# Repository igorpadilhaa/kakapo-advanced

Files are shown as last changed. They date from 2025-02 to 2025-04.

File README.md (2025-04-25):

---

# Projeto-VictorC-RyanK-IgorP_UFRR_2024

<br />  
<p align="center">
  <a href="">
    
    
    
  </a>
  <h1 align="center">Projeto Pulseira Inteligente</h1>
  <p align="center">
    
  </p>

## 1. Pulseira Inteligente para Monitoramento de Temperatura e Cor da Pele

O projeto consiste no desenvolvimento de uma **pulseira inteligente** para monitoramento de **temperatura corporal** e **variação na coloração da pele**, com foco na **detecção de icterícia e cianose**, utilizando o microcontrolador **ESP32 Pico**.

### 1.1 Objetivos:
- Criar uma pulseira vestível e funcional para uso em ambientes de saúde pública.
- Monitorar a temperatura corporal utilizando sensor **NTC de 5k**.
- Analisar a coloração da pele com o sensor **TCS3200**.
- Utilizar inteligência artificial para identificar variações de cor associadas a **icterícia** e **cianose**.
- Estimar o **grau de variação** da coloração da pele: `Estável`, `Leve`, `Mediana` ou `Alta`.
- Permitir identificação rápida do paciente via **tag RFID**.

## 2. Fluxo de Uso:
- O paciente recebe uma pulseira com sua tag RFID.
- A pulseira coleta periodicamente a **temperatura corporal** e a **cor da pele (RGB)**.
- Os dados são enviados para o banco de dados em nuvem.
- A **IA processa os dados** e identifica se há variação significativa na cor da pele.
- Se detectada, a IA classifica:
  - **Se é icterícia ou cianose**.
  - **Grau da variação** da condição.

## 3. Funcionamento:
- A pulseira tem um ID único salvo em sua tag RFID.
- Os dados coletados (temperatura e cor da pele) são enviados via Wi-Fi para o **Realtime Database**.
- O sensor **TCS3200** coleta as cores RGB da pele.
- Uma **rede neural** compara os valores anteriores e atuais, enquanto uma **floresta randômica (Random Forest)** classifica o **grau da alteração**.
- O sistema já é capaz de identificar casos de:
  - **Icterícia** (coloração amarelada)
  - **Cianose** (coloração azulada)
- A pulseira pode ser lida com um dispositivo com leitor RFID e display, que consulta os dados do paciente diretamente no banco de dados.

## 4. Tutorial de Montagem:
- **NTC de 5k (Sensor de Temperatura)**: Conectar ao pino **23** do ESP32 Pico. Utilizar resistor de **5kΩ** em paralelo.
- **Sensor TCS3200 (Sensor de Cor)**: Conectar os pinos S0–S3 e OUT aos pinos digitais do ESP32 Pico.
- **RFID**: Utilizar um leitor compatível com SPI, conectando os pinos ao ESP32 Pico.
- **Alimentação**: Bateria ligada ao **TP4056**, passando por um **switch**, conectando ao **VIN (5V)** do ESP32.
- **Botão**: Um lado no **GND**, outro na **porta 2** do ESP32.
- **LED Indicador**: Com resistor de **330Ω**, conectado à **porta 4** do ESP32.

## 5. Mudanças Implementadas:
- Substituição do Arduino Mega pelo **ESP32 Pico**.
- **Remoção do aplicativo de monitoramento**.
- **Remoção do sensor de batimentos MAX30100**.
- **Adição do sensor TCS3200** para análise da coloração da pele.
- **Implementação da IA** (rede neural + floresta randômica).
- Sistema já é capaz de **detectar e classificar** casos de **icterícia e cianose** com base na variação da cor da pele.

## 6. Possíveis Atualizações Futuras:
- Adição do sensor **MAX30120** para retomada do monitoramento cardíaco.
- Expansão do modelo de IA para detecção de **doenças dermatológicas mais complexas**, como **câncer de pele**.
- Melhorias no consumo de energia e integração de baterias recarregáveis de longa duração.

---

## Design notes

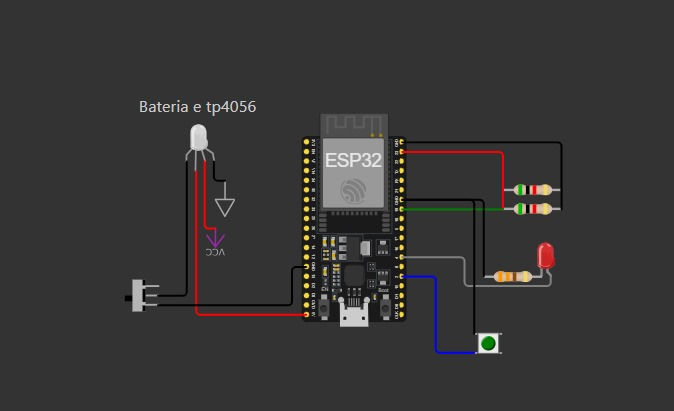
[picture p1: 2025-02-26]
Imagens/circuito.png

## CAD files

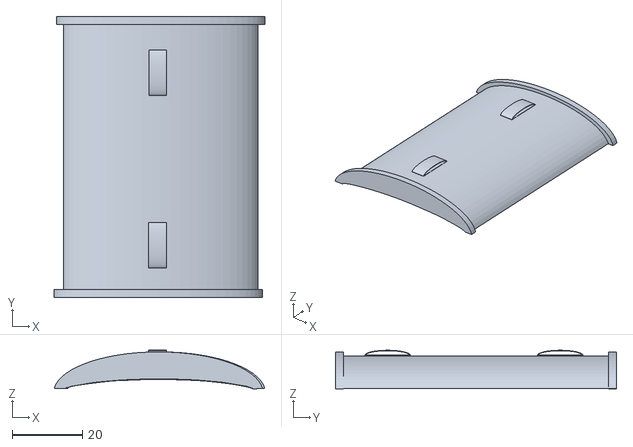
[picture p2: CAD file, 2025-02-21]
ModelagensTeste1/Pulseira kakapo(1).stl
60.0 x 80.0 x 11.0

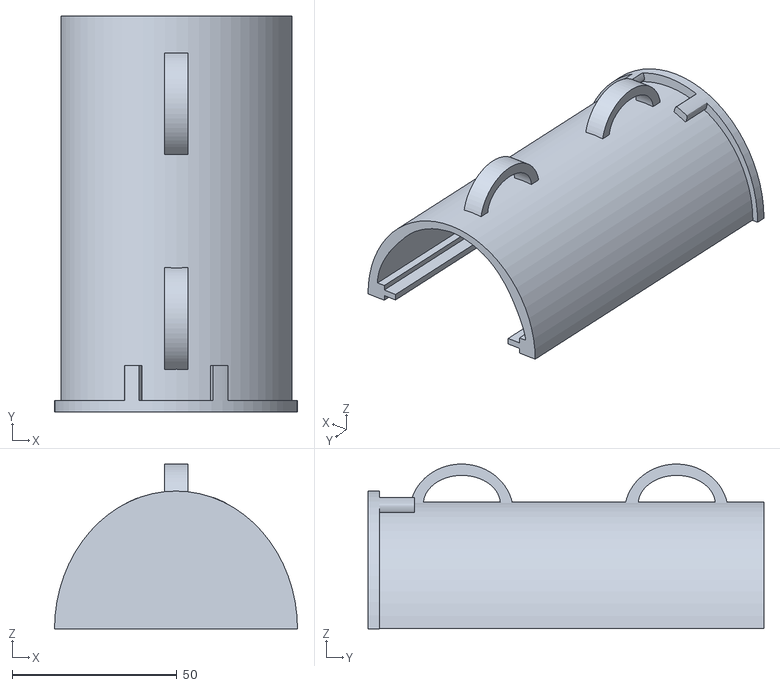
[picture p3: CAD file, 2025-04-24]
Modelos 3d/Parte 1.stl
73.7 x 120.0 x 50.0

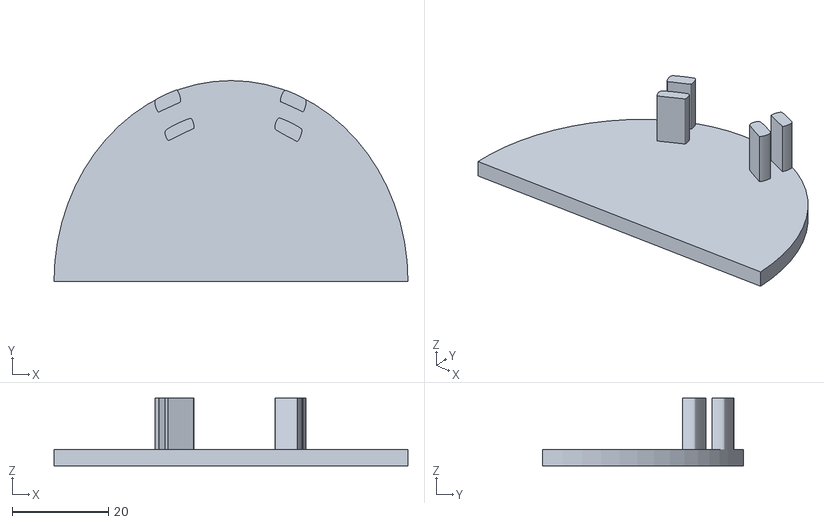
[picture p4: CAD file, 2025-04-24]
Modelos 3d/Parte 2.stl
73.7 x 41.8 x 14.1

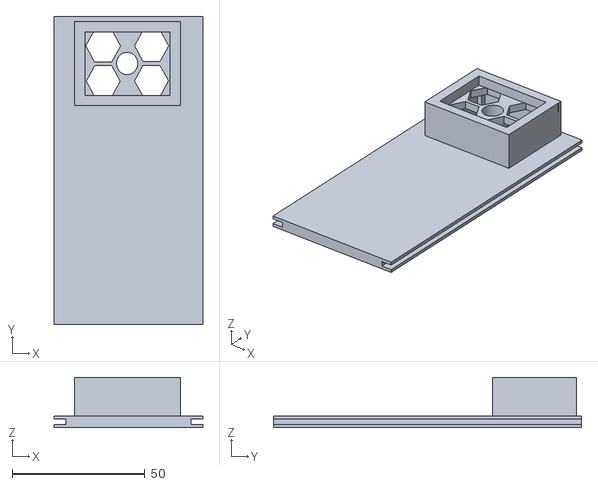
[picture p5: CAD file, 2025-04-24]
Modelos 3d/Parte 3.stl
56.1 x 115.9 x 19.0

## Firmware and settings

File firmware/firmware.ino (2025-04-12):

#include <WiFi.h>
#include <HTTPClient.h>
#include <ArduinoJson.h>

const char* ssid = "SSID";
const char* password = "PASSWORD";

String serverName = "FIREBASE_URL";

const int ntcPin = 34;
const float seriesResistor = 10000.0;     // Resistor fixo (em ohms)
const float nominalResistance = 10000.0;  // Resistência nominal do NTC a 25°C
const float nominalTemperature = 25.0;    // Temperatura nominal em graus Celsius
const float bCoefficient = 3950.0;        // Coeficiente Beta do NTC
const float realSupplyVoltage = 3.3;      // Tensão de alimentação real do ESP32 (em volts)

#define S0 4
#define S1 7
#define S2 8 
#define S3 5
#define OUT 22

void setup() {
  Serial.begin(115200);
  
  WiFi.begin(ssid, password);
  while (WiFi.status() != WL_CONNECTED) {
    delay(1000);
    Serial.println("Conectando-se ao Wi-Fi...");
  }
  
  Serial.println("Conectado ao Wi-Fi!");
  Serial.print("Endereço IP: ");
  Serial.println(WiFi.localIP());

  pinMode(ntcPin, INPUT);

  pinMode(S0, OUTPUT);
  digitalWrite(S0, HIGH);

  pinMode(S1, OUTPUT);
  digitalWrite(S1, LOW);

  pinMode(S2, OUTPUT);
  pinMode(S3, OUTPUT);
  pinMode(OUT, INPUT);
}

void loop() {
  float t = ler_temperatura();
  
  unsigned int red, green, blue;
  ler_cor(red, green, blue);

  registrar(t, red, green, blue);

  Serial.print("Temperatura: ");
  Serial.print(t);
  Serial.println(" °C");
  delay(5000);
}

float ler_temperatura() {
  int analogValue = analogRead(ntcPin);
  
  float voltage = analogValue * (realSupplyVoltage / 4095.0);

  Serial.print("Tensão medida no pino: ");
  Serial.print(voltage);
  Serial.println(" V");

  float ntcResistance = seriesResistor * (realSupplyVoltage / voltage - 1);

  Serial.print("Resistência do NTC: ");
  Serial.print(ntcResistance);
  Serial.println(" ohms");

  float temperatureKelvin = 1.0 / (1.0 / (nominalTemperature + 273.15) + 
                        (1.0 / bCoefficient) * log(ntcResistance / nominalResistance));

  float temperatureCelsius = temperatureKelvin - 273.15+6;
  return temperatureCelsius;
}

void registrar(float temperatura, unsigned int red, unsigned int green, unsigned blue) {
  StaticJsonDocument<200> jsonDoc;
  StaticJsonDocument<200> arrayBuf;

  JsonArray array = arrayBuf.to<JsonArray>();
  array.add(red);
  array.add(green);
  array.add(blue);

  jsonDoc["temperatura"] = temperatura;
  jsonDoc["rgb"] =  array;
  
  String jsonString;
  serializeJson(jsonDoc, jsonString);
  
  HTTPClient http;
  http.begin(serverName + "/pulseira/73b06a10.json" );
  http.addHeader("Content-Type", "application/json");

  int httpCode = http.PUT(jsonString);
  Serial.print("Resposta: ");
  Serial.println(httpCode);

  String payload = http.getString();
  Serial.println("- payload: ");
  Serial.println(payload);
  
  http.end();
}

void ler_cor(unsigned int &red, unsigned int &green, unsigned int &blue) {
  digitalWrite(S2, LOW); digitalWrite(S3, LOW);
  red = pulseIn(OUT, LOW);

  digitalWrite(S2, HIGH); digitalWrite(S3, HIGH);
  green = pulseIn(OUT, LOW);

  digitalWrite(S2, LOW); digitalWrite(S3, HIGH);
  blue = pulseIn(OUT, LOW);

  String json = "{\"red\":" + String(red) + ",\"green\":" + String(green) + ",\"blue\":" + String(blue) + "}";
  Serial.println(json);

  red = map(red, 3460, 743, 0, 255);
  green = map(green, 2450, 1860, 0, 255);
  blue = map(blue, 2830, 1250, 0, 255);

  json = "{\"red\":" + String(red) + ",\"green\":" + String(green) + ",\"blue\":" + String(blue) + "}";
  Serial.println(json);
}
